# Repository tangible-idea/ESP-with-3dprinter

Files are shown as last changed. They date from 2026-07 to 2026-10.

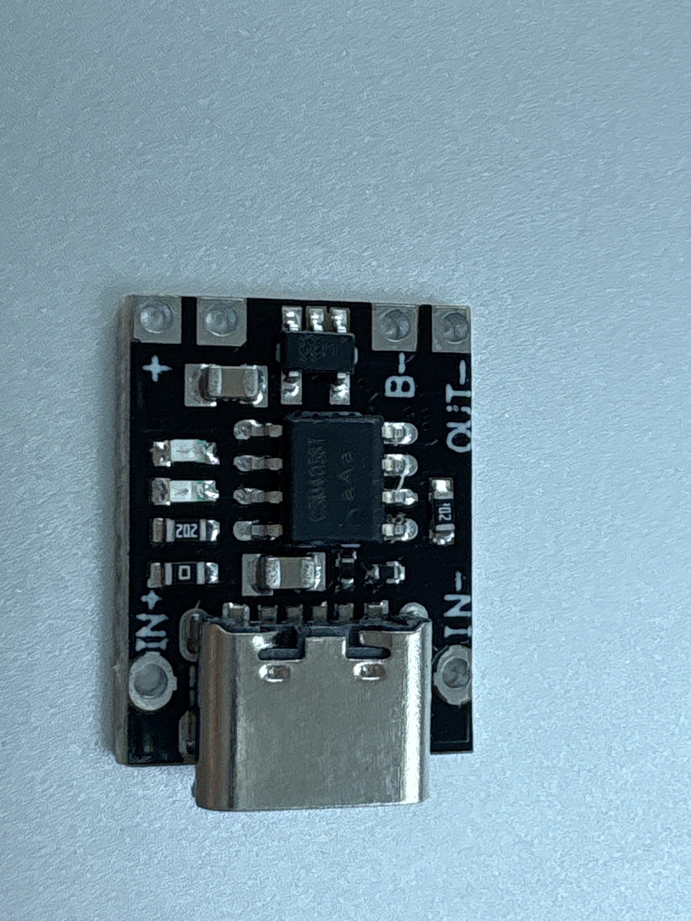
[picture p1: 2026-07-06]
hardwares/battery_charging_module.jpeg

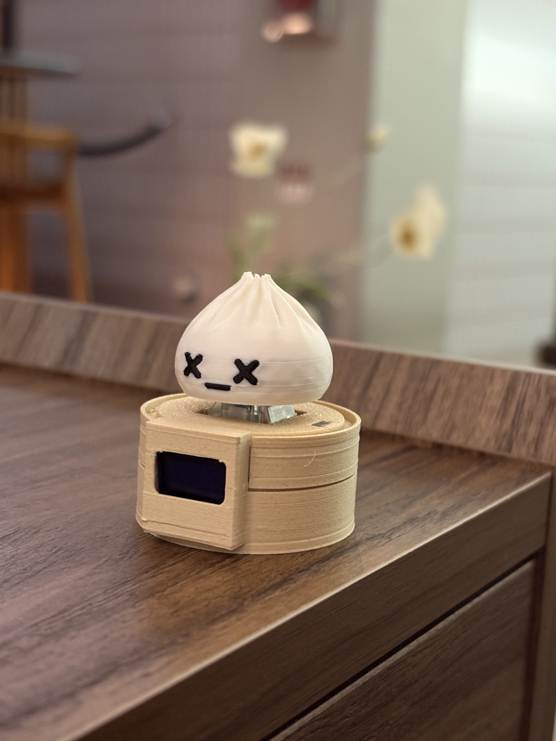
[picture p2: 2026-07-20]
hardwares/IMG_5292.jpg

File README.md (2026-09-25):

# 🥟 딤섬 클리커 (Dimsum Clicker)

딤섬 찜기 모양의 3단 적층형 하드웨어 케이스. ESP32-C3 + 520mAh 배터리 + OLED + 키보드 스위치를 담아
누르면 반응하는 미니 가젯을 만드는 프로젝트입니다.

**브라우저에서 슬라이더로 케이스를 실시간 재설계**하고 층별 STL을 바로 뽑을 수 있는 웹 컨피규레이터가 핵심입니다.

컨피규레이터의 제품 선택 메뉴에는 다음 독립 설계도 함께 들어 있습니다.

- **투두 서포터** — 아이맥 하단 모서리에 끼우는 ESP32/OLED 클립
- **운동 모션 센서** — 운동기구에 30×10×2mm 자석으로 붙이고 MPU6050으로 상하 움직임을 측정. 선택형 KY-035(15×19)는 내장 자석 옆에 세워 장착/분리를 판정합니다. 선택형 0.96" OLED는 뚜껑 위 보호 림에 끼우며 23.2×12.4mm 화면이 위로 보이고, MPU6050과 GPIO8/9 I2C 버스를 공유합니다. 기본 외형은 47×31×33.9mm입니다.

```
1층 (배터리)  ─  2층 (ESP32 · 충전모듈 · OLED · USB)  ─  3층 (뚜껑 + 스위치 스탠드 + 딤섬 캐릭터)
```

---

## 실행 방법

브라우저(three.js + WASM) 앱이라 **로컬 웹 서버만 있으면** 됩니다. 별도 설치·빌드가 없습니다.

```bash
# 1) 프로젝트 루트에서 실행 (stl_files/ 를 읽어야 하므로 반드시 루트에서)
cd ESP-with-3dprinter
python3 -m http.server 8123

# 2) 브라우저에서 접속
#    http://localhost:8123/web/
```

> Python이 없으면 아무 정적 서버나 가능합니다 — 예: `npx serve` 후 `/web/` 경로로 접속.
> 필요한 라이브러리(three.js·manifold WASM 등)는 전부 `web/vendor/`에 포함되어 있어 **인터넷 없이도** 동작합니다.

### 쓰는 순서

1. 왼쪽 패널에서 모양(둥근 네모/원형)·크기·층 높이·부품 위치를 조정 → 3D 미리보기가 실시간 갱신
2. `배선 표시`를 켜면 배터리→충전모듈→ESP32→OLED→스위치 배선이 색깔 전선으로 표시됨
   (보라 스위치 · 초록 SDA · 주황 SCL 전선을 **우클릭**하면 GPIO 핀 변경)
3. `분해 ⟷ 조립` 슬라이더로 조립 상태 확인, 하단의 `조립 간섭 없음 ✓` 확인
4. `STL 내보내기`에서 1·2·3층을 각각 다운로드 → 슬라이서로 출력
5. 마음에 드는 설정은 `프리셋 → 내보내기`로 .json 저장 (설정은 자동으로도 저장됨)

전체 기능 설명은 [`web/README.md`](web/README.md) 참고.

---

## 프로젝트 구조

| 경로 | 내용 |
|---|---|
| `web/` | **웹 컨피규레이터** (메인). `index.html` + `app.js` + `vendor/`(로컬 라이브러리) |
| `generate_dimsum_clicker.py` | 파이썬 STL 생성기 (웹과 동일한 manifold 엔진, 배치 출력용) |
| `stl_files/` | 부품 실측 STL (배터리·충전모듈·ESP32·스위치 스탠드·OLED·USB 구멍) — 케이스 절삭/배치 기준 |
| `hardwares/` | 부품 데이터시트/사진 (핀아웃, 치수) |
| `dimsum/` | 딤섬 캐릭터·클릭 캡 STL |
| `my_designs/` | 초기 손 모델링 참고본 (원형 다마고치 스타일 등) |

---

## 두 가지 생성 방식

- **웹 컨피규레이터** (`web/`) — 실시간 파라메트릭. 슬라이더로 조정하고 즉시 STL 다운로드. 평소엔 이걸 쓰세요.
- **파이썬 생성기** (`generate_dimsum_clicker.py`) — 고정 파라미터로 배치 생성.
  ```bash
  pip3 install --user trimesh manifold3d shapely
  python3 generate_dimsum_clicker.py   # output_stl/ 에 층별 STL 생성
  ```

둘 다 **manifold WASM/라이브러리**로 CSG 연산을 해서 출력 STL이 항상 watertight(출력 가능)입니다.

---

## 필요한 하드웨어 (BOM)

| 부품 | 사양 | 케이스 반영 |
|---|---|---|
| ESP32-C3 SuperMini | 24 × 18 × 4.2mm | 2층 포켓 + 핀아웃 기반 배선 |
| 리튬 배터리 | 520mAh 36.5 × 28.5 × 4.3mm / 302030 135mAh 32 × 20 × 4mm / 14280 350mAh Ø14.2 × 28.2mm / 16340 Ø16.7 × 37.4mm / 3.7V 10180 100mAh Ø10 × 18mm (원통형) / 650mAh 40 × 20 × 8mm | 선택한 규격으로 1층 테두리 또는 2층 세움 포켓 생성 |
| 충전모듈 | 기존 STL 19 × 14 × 4.5mm (칩명 미확인) / TP4056 USB-C 27 × 17.3 × 4.0mm | 2층, 선택한 모듈 치수에 맞춰 포켓과 USB 포트 생성. TP4056 실물 치수 확인 필요 |
| OLED 디스플레이 | 0.49" (15×16) 또는 0.96" (26×26) | 2층 타워에 뒤에서 삽입, 창으로 화면 노출 |
| 키보드 스위치 + 스탠드 | 17.79 × 14.3, 높이 11mm | 3층 뚜껑에 실물 형상대로 구멍 |

배선(웹의 `배선 표시` 참고). 기본 핀 배정은 **펌웨어 쪽 배선도(`wiring.html`)와 동일**합니다 — 모든 핀은 3D 뷰에서 전선/라벨 우클릭으로 변경 가능:
- 배터리 +/− → 충전모듈 **B+/B−**
- 기존 충전모듈 **OUT+/OUT−** → ESP32 **5V/GND** (기존 배선 표시). TP4056 선택 시 OUT은 배터리 전압이므로 5V 직결 안내를 표시하지 않으며, ESP32 전원 입력/필요한 승압 회로와 배터리별 충전 전류를 별도로 확인해야 함
- ESP32 **3V3·GND·GPIO8·GPIO9** → OLED **VCC·GND·SDA·SCL** (I2C)
- 스위치 2가닥 → ESP32 **GPIO3 + GND** (극성 무관 / 스위치 2개 모드는 두 번째가 **GPIO4**)
- 2×5 투톤 LED → **GPIO7 = 빨강(1번 핀, 1kΩ)**, **GPIO6 = 초록(3번 핀, 220Ω)**, 공통 캐소드(2번 핀) → GND
- 피에조 부저 + → **GPIO2** (PWM 톤), − → GND

여유 핀: **0 · 1 · 5 · 10 · 20 · 21**

```cpp
// 펌웨어 예시
Wire.begin(8, 9);          // SDA, SCL — 웹에서 바꾼 핀 그대로
pinMode(3, INPUT_PULLUP);  // 스위치: 눌리면 LOW
// GPIO2는 ESP32-C3 스트래핑 핀 — 부팅이 불안정하면 여기부터 의심
```

---

## 출력 & 조립 팁

- **1·2층은 그대로**, **3층만 뒤집어서** 출력 (상판이 베드에 닿게 — 서포트 불필요). 내보내기의 `3층 출력용 뒤집기` 체크가 처리해 줌.
- **V형 결합부**(기본 켜짐)를 쓰면 2층 밑면 결합 홈에 **서포트가 필요 없고** 층이 얹을 때 자가 정렬됩니다.
- 층이 **헐거우면** `결합 유격`을 낮추고(기본 0.08mm), **안 들어가면** 올리세요. 프린터 수축에 맞춰 조정.
- **딸각 결합**(기본 켜짐, 1↔2↔3층)은 네 코너에 **캔틸레버 스냅 후크**를 만듭니다.
  아래층 상판에서 두께 1.0mm 탄성 팔이 올라가고, 팔 끝 바깥면의 45° 비드가 위층 벽 안쪽 포켓에 물립니다.
  휘는 건 강체 턱이 아니라 팔이라서 **걸림 깊이를 0.5mm** 로 잡을 수 있습니다(강체 rabbet 에 돌기만 붙이면 0.2mm 가 한계).
  기본값에서 조립력은 층당 대략 **1~2kgf**, 팔 굽힘 변형률 0.9~1.5% (PLA 안전 범위).
  - `걸림 깊이` ↑ = 더 단단히 잡힘 / `탄성 팔 길이` ↑ = 더 부드럽게 눌림
  - 팔 길이는 위층 벽 안에 들어가도록 자동 클램프 → 낮은 층은 팔이 짧고 뻣뻣해집니다(경고로 표시)
  - 코너를 쓰는 이유: 어떤 설정에서도 USB·OLED·스위치가 닿지 않는 유일한 자리
  - 4층 뚜껑은 턱·홈만 유지합니다 — 뚜껑은 턱이 베드에 닿게 출력하므로 그 아래로 팔을 더 내릴 수 없습니다
- 각 층은 딤섬 찜기처럼 **얹으면 맞물리는** 구조라 나사·접착 없이 조립됩니다.

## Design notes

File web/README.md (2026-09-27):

# 🥟 딤섬 클리커 웹 컨피규레이터

브라우저에서 슬라이더로 케이스를 실시간 재설계하고 층별 STL을 바로 다운로드합니다.

## 실행

```bash
# 프로젝트 루트에서 (stl_files/ 를 읽어야 하므로 반드시 루트에서)
python3 -m http.server 8123
```

브라우저에서 <http://localhost:8123/web/> 접속.

## 기능

- **제품 선택**: 딤섬 클리커 / 투두 서포터 / **운동 모션 센서**. 운동 센서는 TW802040 배터리(40×20), KY-035(15×19), 선택형 0.96" OLED를 위한 3단 적층형입니다. ESP32-C3 SuperMini를 선택하면 TP4056과 MPU6050이 트레이에, SuperMini가 뚜껑에 놓입니다. Seeed XIAO ESP32C3를 선택하면 충전모듈 자리에 놓습니다. XIAO 포켓 기본값은 긴 변 X(USB 끝↔반대쪽) **22.5mm**, 짧은 변 Y(양쪽 핀 열 사이) **17.8mm**이며 두 치수를 0.1mm씩 조절할 수 있습니다. USB 개구부는 원래 나팔형 구멍보다 폭 약 0.4mm, 높이 약 0.36mm 줄였습니다. 배선 구멍은 D2/D3 근처의 보드 뒷면 B+/B− 패드 아래에 있습니다. 배터리 두 선은 D2/D3 핀이 아닌 B+/B−에 직접 연결하며 XIAO의 USB-C로 충전합니다. 이 배치에서 별도 충전모듈과 전원 스위치 자리, 뚜껑의 SuperMini 케이지는 빠집니다. **ESP 수납부 높이** 슬라이더는 선택한 보드의 수납 공간과 케이스 전체 높이를 함께 조절합니다(기본 4.6mm). OLED는 뚜껑 위에 놓이고 MPU6050과 GPIO8/9 I2C 버스를 공유합니다.

  KY-035는 3V3/GND와 아날로그 출력(GPIO0 같은 ADC 핀)으로 연결합니다. 부팅 시 내장 자석만 있는 기준값을 평균내고, 외부 자석을 붙인 상태의 값을 별도로 학습한 뒤 두 값의 중간값에 히스테리시스와 50~100ms 디바운스를 적용하면 운동 시작/끝점 오검출을 줄일 수 있습니다. 외부 자석 극성에 따라 값이 증가하거나 감소할 수 있으므로 변화 방향도 함께 저장해야 합니다.

- **모양**: 둥근 네모 / **완전 원형(딤섬 찜기)** — 원형은 W가 지름이 되고(기본 Ø54, 배터리 대각선 46.3mm 때문에 하한) D·모서리는 비활성. 원형에서는 충전모듈이 항상 중앙(Y 고정)이고 동쪽 벽에 폭 18mm 플랫 USB 패드가 생김(my_designs/rounded.png 참조). OLED 안착면은 곡률에 맞춰 자동 계산됨
- **외곽 디자인**: 가로/세로/모서리 둥글기/벽 두께/결합 유격. 결합 유격(기본 0.08mm)을 줄일수록 층이 꽉 끼움
- **V형 결합부** (기본 켜짐): 층간 홈·턱을 58° 계단 단면으로 만들어 위층 밑면에 서포트가 필요 없음 + 조립 시 자가 정렬. 끄면 기존 사각 단면
- **설정 자동 저장**: 모든 값이 localStorage에 저장되어 리로드해도 유지, '설정 초기화' 버튼으로 기본값 복원
- **미세조절**: 각 슬라이더 좌우 −/+ 버튼으로 step 단위 정밀 조정
- **프리셋 import/export**: 전체 설정을 .json 파일로 저장/불러오기 (여러 디자인 파일 관리)
- **층 높이**: 1·2·3층 + 스위치 보스 높이/스탠드 매립 깊이
- **부품 배치**: 3층 MX 스위치 X/Y(더블 모드는 두 스위치 묶음이 함께 이동), ESP32 위치·회전, 충전모듈 종류(기존 19×14×4.5 / TP4056 USB-C 27×17.3×4.0)와 Y(USB는 항상 동쪽 벽), 배터리 종류(520mAh 36.5×28.5×4.3 / 302030 135mAh 32×20×4 / 원통형 14280 350mAh Ø14.2×28.2 / 원통형 16340 Ø16.7×37.4 / 원통형 3.7V 10180 100mAh Ø10×18 / 650mAh 40×20×8) 및 1층 가로(긴 변 X)·세로(긴 변 Y)·2층 세움, OLED 종류(0.49" 15×16 / 0.96" 26×26)와 벽 선택(서쪽 기본 = USB 반대), 배선구멍 위치·방향(14×5 / 5×14 / 5×17 슬롯 — 배터리 +/− 두 가닥이 함께 통과). TP4056 옵션은 별도 실측 보드 외형이며 제품마다 크기·핀 배열이 다를 수 있어 실물 확인 필요
- **0.96" OLED**: 표시영역 22.74×11.86에 맞는 큰 창 + 모서리 4홀(22×22mm)에 맞는 Ø1.8 위치결정 핀 4개가 포켓 안에 자동 생성. 모듈이 26mm로 커서 타워가 높아지므로 2·3층 높이 경고를 확인할 것
- **OLED 타워 결합**: OLED는 타워 뒤(내부)에서 통째로 밀어 넣음 — 뒷면 완전 개방(15.5×16.3), 앞은 벽+디스플레이 창이 잡아줌. OLED 소켓은 2층 높이와 무관하게 항상 21.2mm 타워로 서고, 2층 벽보다 높으면 3층 뚜껑에 타워 모양 노치가 자동으로 커팅되어 끼워짐(조립 키 역할). 덕분에 2층을 16mm까지 낮출 수 있음
- **분해 ⟷ 조립** 슬라이더 + 애니메이션, 부품 고스트 표시, 케이스 반투명(X-ray)
- **배선 시각화** ('배선 표시' 토글): 실제 핀 배치 기반 전선 가이드 — 배터리 +/− → (2층 배선구멍 경유) → 충전모듈 B+/B−, 기존 모듈 OUT+/OUT− → ESP32 5V/GND, ESP32 3V3/GND/GPIO8/GPIO9 → OLED VCC/GND/SDA/SCL, 스위치 2가닥 → GPIO/GND (극성 무관, 3층 상판 중앙 통로 경유, 기본 G3), 2×5 투톤 LED → G7 빨강 / G6 초록 / 공통 캐소드 GND, 부저 + → G2. TP4056은 OUT이 안정화된 5V가 아니므로 ESP32 5V 직결선을 생략하고 전원 입력/승압 회로 확인 경고를 표시함. 기본 핀맵은 펌웨어 배선도(`wiring.html`)와 동일.
- **GPIO 핀 우클릭 변경**: 스위치·SDA·SCL 세 전선 모두 **우클릭하면 GPIO 선택 메뉴**가 뜨고, 고른 핀의 실제 위치로 전선이 이동. ESP32-C3는 I2C도 소프트웨어 핀이라 SDA/SCL도 자유 배정. 다른 전선이 쓰는 핀은 회색으로 비활성화되어 충돌 방지. 기본 스위치=G3(2개 모드 두 번째=G4), SDA=G8, SCL=G9, LED 빨강=G7, LED 초록=G6, 부저=G2 색상: 빨강 +, 검정 −, 초록 SDA, 주황 SCL, 보라 GPIO. 핀 라벨 스프라이트 포함, 분해 뷰를 따라감
- **부저 핀 구멍**: 2층 바닥 세움은 받침 바닥을 관통하는 구멍 2개, 2층 눕힘은 핀이 나오는 +X 끝면의 축방향 구멍 2개. 기본 핀 간격 6.5mm·구멍 Ø1.5mm이며 설정에서 실물 치수에 맞출 수 있음. 3층 천장 매달림은 핀이 빈 공간을 향해 상판을 뚫지 않음. NFC 포켓과 겹치면 경고 표시
- **측면 텍스처 (Weave 1·2·3 · Wood 1)**: 버튼 하나로 케이스 **바깥 옆면에만** 무늬를 새김. **케이스 외곽선(원통/둥근 네모) 위에 있는 면에만** 들어감 — OLED 타워·커버, 플랫 USB 패드, 결합 턱/홈처럼 외곽선에서 벗어난 면과 위·아래 면, 포켓 안쪽 벽은 매끈하게 남아서 층 결합·부품 끼움이 그대로 유지되고, 무늬는 **안쪽으로만** 파내므로 바깥 치수도 커지지 않음. 깊이·무늬 크기·디테일(mm/삼각형) 조절 가능. 무늬를 고르면 그 이미지에 맞는 무늬 크기·디테일이 자동으로 들어감 — 이미지 한 장 안의 반복 횟수가 달라서(Weave1 8회 / Weave2 6회 / Weave3 12회 / Wood1 29회) 같은 값을 쓰면 Weave3·Wood1 은 무늬 한 칸이 1mm 아래로 잘아져 뭉개짐. Wood 1 은 흑백 2치 나뭇결이라 결이 가로로 케이스를 감아 돎(tile 36 / 디테일 0.4) 무늬가 켜져 있으면 슬라이더를 드래그하는 동안에는 형상만 빠르게 갱신하고, 손을 떼면 CSG를 다시 돌리지 않고 무늬만 다시 입힘
- **조립 간섭 자동 검사**: 리빌드마다 층간 교집합 부피를 계산해 하단에 "조립 간섭 없음 ✓" 표시
- **STL 내보내기**: 층별 다운로드, 3층은 출력용 뒤집기 옵션 (크롬이 연속 다운로드를 차단하면 주소창의 다운로드 아이콘에서 허용)
- 배터리/부품이 안 들어가는 조합이면 하단에 경고 표시

## 구현

- CSG 엔진: **manifold WASM** (`vendor/manifold.wasm`) — 파이썬 생성기(`generate_dimsum_clicker.py`)와 동일 엔진이라 출력 STL이 항상 watertight
- 3층 스위치 자리는 `stl_files/keyboard_switch_stand.stl` 실물 메시를 3.5% 팽창시켜 그대로 boolean 절삭 → 스탠드가 보스에 자연스럽게 매립
- USB 구멍도 `stl_files/usb_c_hole.stl` 실물 형상 사용 (얇은 벽에 맞게 나팔부 60% 압축)
- 모든 라이브러리는 `vendor/`에 로컬 포함 — 오프라인 동작
- 측면 텍스처는 `texture.js` — 꼭짓점 용접 → 옆면 마스크(법선이 거의 수평 + XY 반직선으로 바깥 실루엣만 선별 + 호출부가 준 `opt.skip`: app.js 는 둥근 사각형 부호거리로 "외곽선에서 0.35mm 이내"인 면만 통과시킨다) → red-green 적응 세분화 → 트라이플래너 UV 로 높이맵 샘플 → 수평 법선 방향 변위. 높이맵은 최소/최대가 아니라 2%/98% 지점으로 오토레벨해서 JPEG 잡티가 대비를 잡아먹지 않게 함. 마스크 경계 꼭짓점은 고정이라 watertight 이 유지됨. [CNCKitchen/stlTexturizer](https://github.com/CNCKitchen/stlTexturizer) 의 파이프라인을 참고했고, `textures/` 의 weave 3장 + wood 1장은 해당 저장소(AGPL-3.0)에서 가져온 displacement map

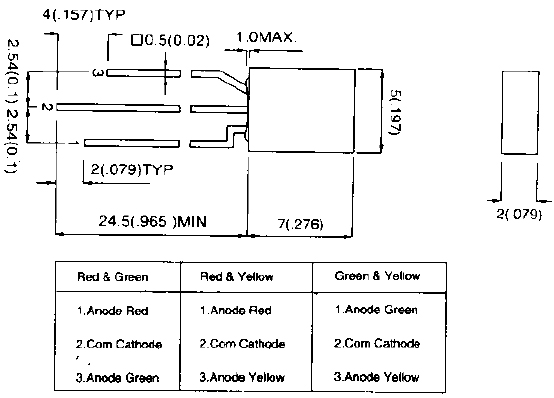
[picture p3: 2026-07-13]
hardwares/led_2x5.png

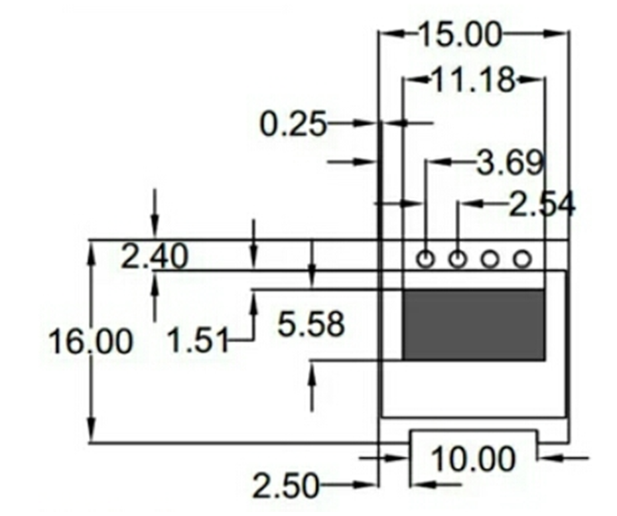
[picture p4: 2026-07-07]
hardwares/oled-0.49.png

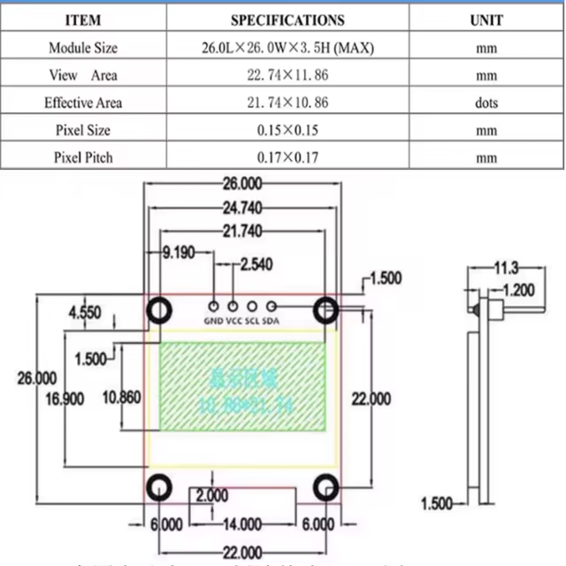
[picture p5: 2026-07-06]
hardwares/oled-0.96.png

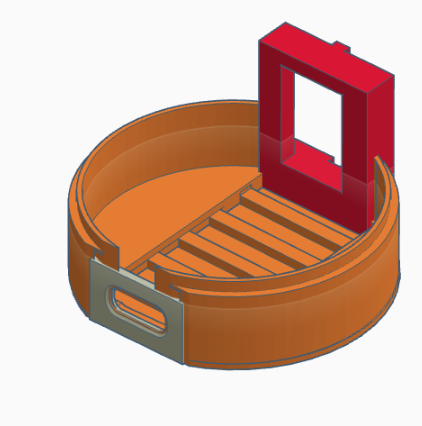
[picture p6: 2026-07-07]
my_designs/rounded.png

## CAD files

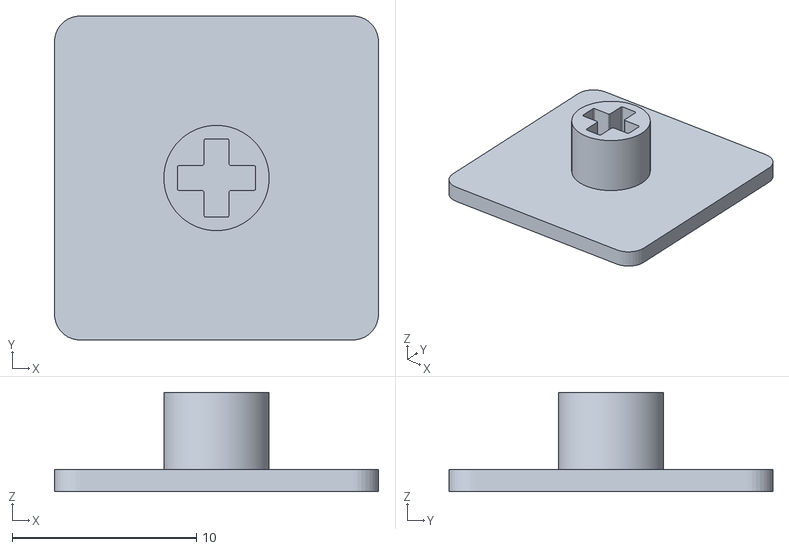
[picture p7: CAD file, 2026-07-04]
dimsum/obj_3_click.stl
17.6 x 17.6 x 5.38

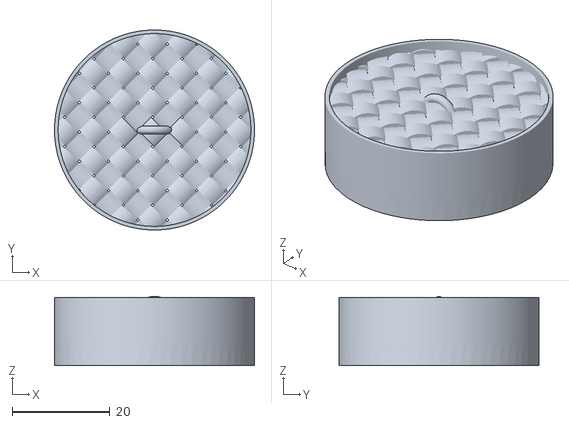
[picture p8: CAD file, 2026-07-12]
my_designs/bun_lid.stl
41.0 x 41.0 x 14.2

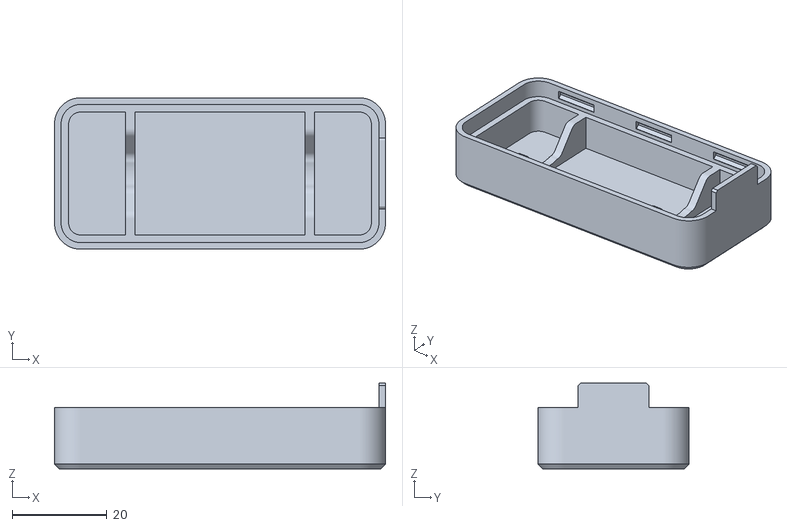
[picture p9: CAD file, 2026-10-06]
my_designs/moisture/xiao-soil-sensor-buttom-3d-printed.stl
70.0 x 32.0 x 18.1

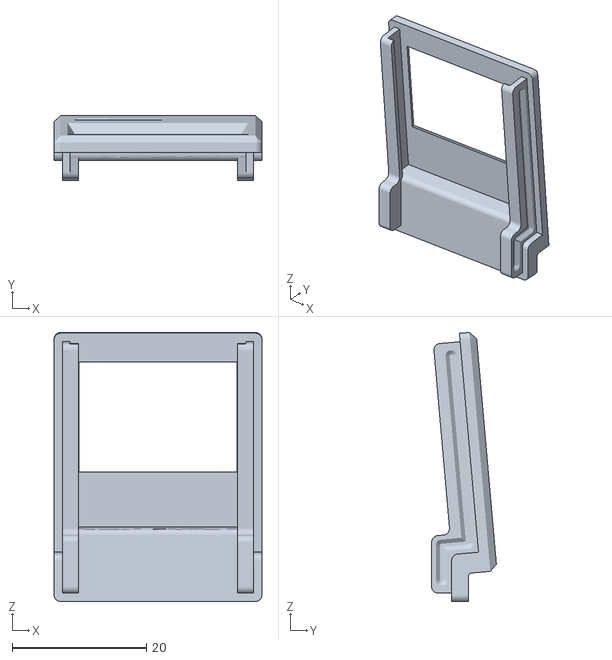
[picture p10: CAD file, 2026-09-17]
stl_files/Tinytosh+-+Cover.stl
31.0 x 9.66 x 40.1

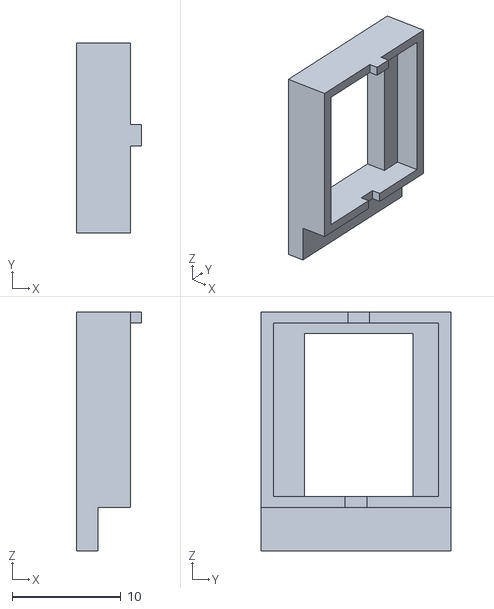
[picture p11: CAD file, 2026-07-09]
web/Project Gasi (97).stl
6.00 x 17.5 x 22.0

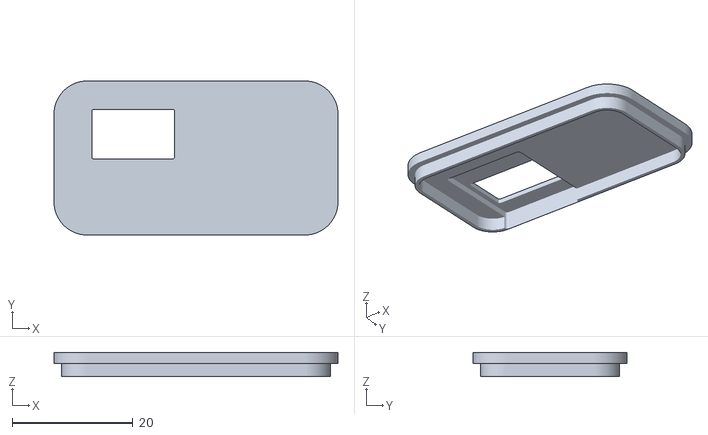
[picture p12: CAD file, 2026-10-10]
workout_sensor_xiao_oled049_lid.stl
47.0 x 25.5 x 4.00

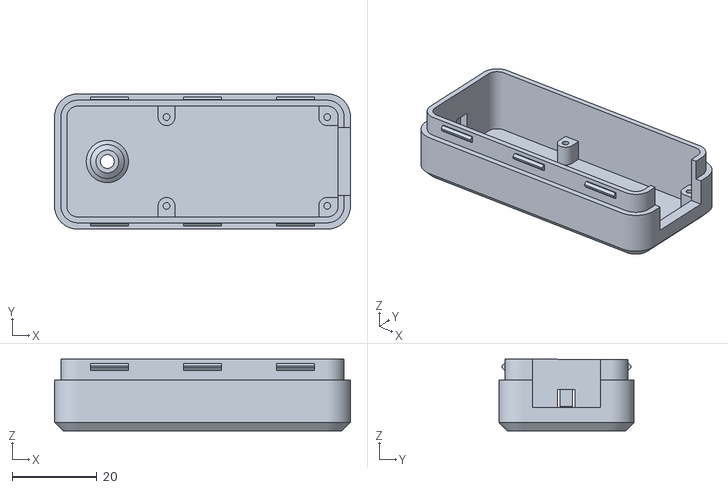
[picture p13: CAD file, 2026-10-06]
my_designs/moisture/xiao-soil-sensor-top-3d-printed.stl
70.0 x 32.0 x 17.0

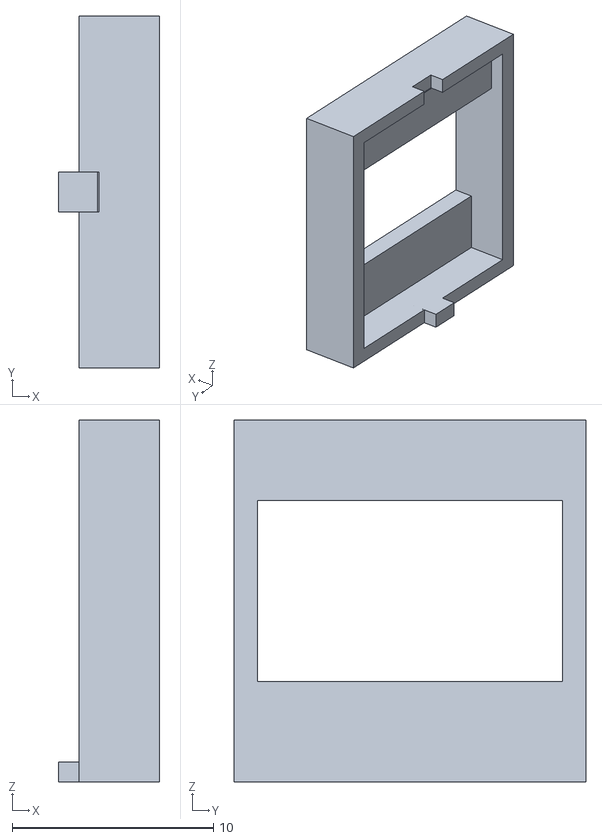
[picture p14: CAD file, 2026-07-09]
my_designs/window_cover_for_oled0.49.stl
5.00 x 17.5 x 18.0

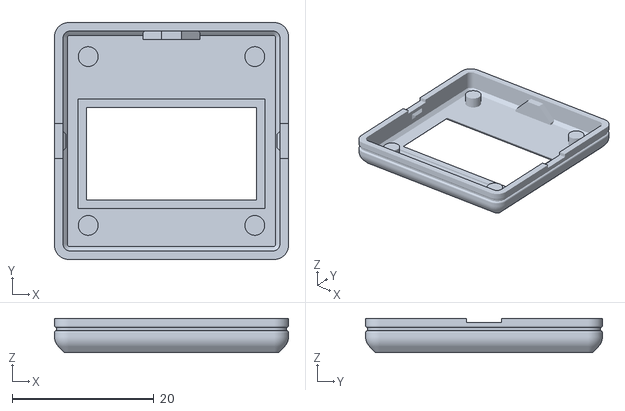
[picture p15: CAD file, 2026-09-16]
stl_files/obj_2_Oled-Lid.stl
33.0 x 33.4 x 4.80

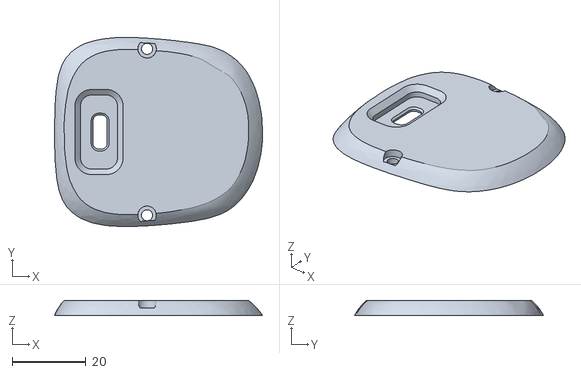
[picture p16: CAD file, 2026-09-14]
stl_files/yeti_cover.stl
56.2 x 51.1 x 4.00

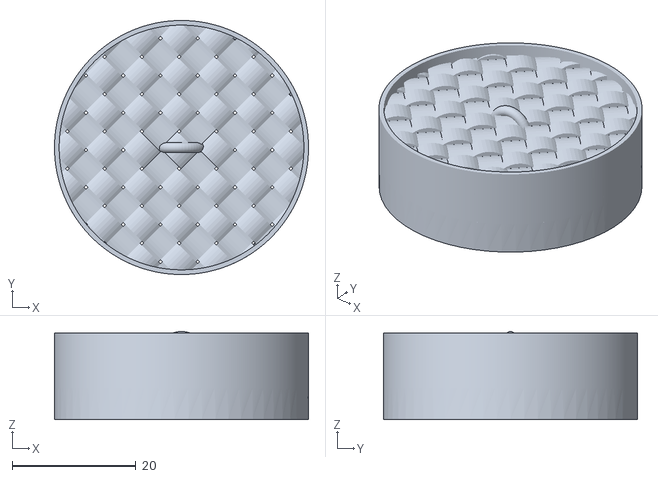
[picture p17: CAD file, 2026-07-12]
web/dist/assets/bun_lid_clean-BYsGTvJL.stl
41.0 x 41.0 x 14.2

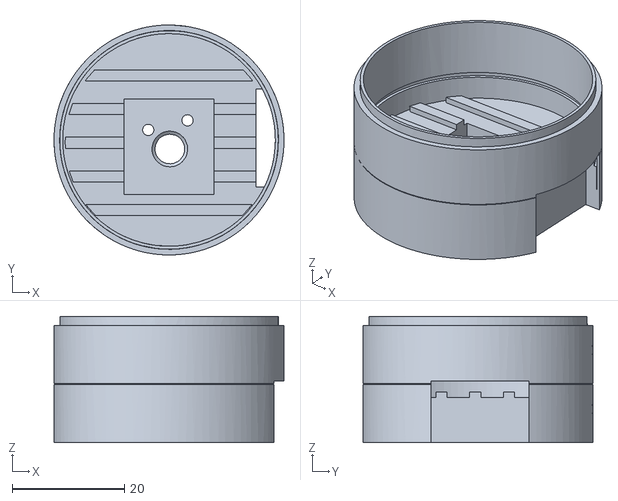
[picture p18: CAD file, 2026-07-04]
my_designs/3rd_floor_keyboard_switch_base.stl
41.0 x 41.0 x 22.5

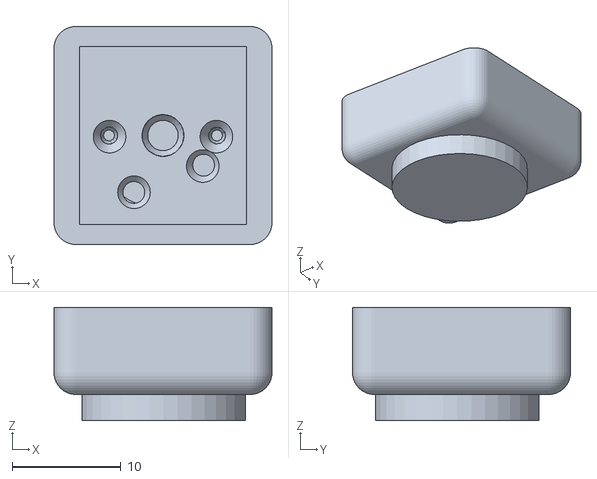
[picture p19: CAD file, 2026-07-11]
stl_files/Mechanical Key Holder V3.stl
20.0 x 20.0 x 10.4

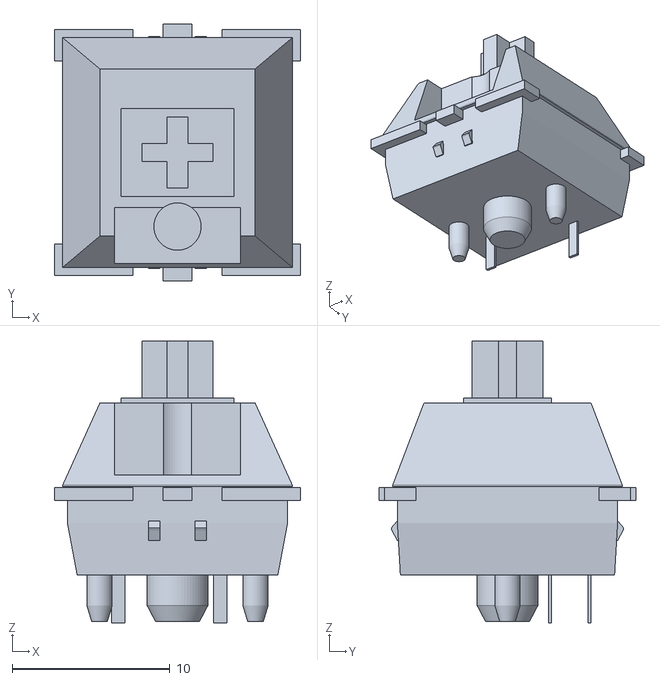
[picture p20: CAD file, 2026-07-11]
web/dist/assets/switch_mx-DlXkNR-Z.stl
15.6 x 16.3 x 17.9

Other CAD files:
my_designs/2nd_floor_esp32_base.stl
stl_files/520Mah_battery.stl
stl_files/keyboard_switch_stand.stl
stl_files/oled_0.49inch.stl
web/dist/assets/battery_charging_module-BhVwN-nm.stl
web/dist/assets/esp32_c3_supermini-DsPQz_9p.stl
web/dist/assets/obj_2_sup 2.0 face-BjSeTE-s.stl
web/dist/assets/usb_c_hole-Bh-LhuL4.stl

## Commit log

2026-07-04 first commit.
    [2nd_floor_esp32_base.stl, 3rd_floor_keyboard_switch_base.stl, 520Mah_battery.stl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]
2026-07-04 사각 모양으로 디자인 변경
    [assembly_preview.stl, floor1_battery.stl, floor2_esp32.stl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]
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2026-07-07 평면 벽 세그먼트를 바닥(z=0)까지 내렸습니다 — 결합 V홈이 이 평면 벽을 자연스럽게 관통하면서 아래층 턱과의 결합도 그대로 유지됩니다
2026-07-07 esp32 와 oled 하단부분이 겹칠떄는 esp32부분 홈을 더 우선적으로 판다.
    [assembly_preview.stl, floor1_battery.stl, floor2_esp32.stl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]
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2026-07-07 수치 조절 pane 쪽 width를 더 넓혀주고, 각 슬라이더에 +, - 를 두어서 미세조절할 수 있게 해줘. 전체 preset을 import export할 수 있게도 해줘
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2026-07-11 oled 벽 두께 수정.
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2026-07-11 2.5층
    [Mechanical Key Holder V3.stl, switch_mx.stl]
2026-07-11 받침선 + USB 앵커 블록 + 셸 실루엣 홈 + 양옆 스냅 립
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2026-07-12 뚜껑 추가
    [bun_lid.stl, bun_lid_clean.stl]
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2026-07-12 추가했습니다. '부품 배치 (2층)'에 ESP32 Z 미세조정 슬라이더(−1 ~ +2, 0.1 단위)가 생겼습니다.
    동작 방식: 슬라이더를 올리면 ESP32가 앉는 포켓 바닥이 그만큼 올라가서(포켓을 얕게 파서) 보드 전체가 위로 올라갑니다. 고스트와 배선 핀 위치도 함께 따라갑니다. 모든 배치 모드에 적용됩니다 — 지금 쓰시는 도킹(USB 직결) 모드는 물론, 눕힘/세움/띄움(2.5층)에서도 동일하게 동작합니다.
    중요한 점 하나: USB 구멍의 z는 일부러 고정했습니다. 실물에서 보드가 낮게 앉아 USB가 구멍 아래쪽에 치우치는 걸 보정하는 게 목적이라, 보드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
2026-07-13 배선 표 안된건가?
    [battery_charging_module-BhVwN-nm.stl, bun_lid_clean-BYsGTvJL.stl, esp32_c3_supermini-DsPQz_9p.stl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]
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2026-07-18 Add a rim ring to steamer floor slats for a level printing surface
    - Adds a border ring at slat height around the steamer floor ribs so the outer edge sits flush with rib tops when printed upside down
    - Grooves are now trimmed to stay inside the ring boundary instead of the old wall/lid offsets
    - Rebuilds web/dist bundle to match
2026-07-19 OLED 분리 포드(소켓형) 추가 + 소켓 슬림화
    - oledPodOn: OLED 타워(창·포켓·핀 포함)를 별도 출력 파트로 분리
    - 텅(전면부)이 벽 관통 개구를 지나 외곽면과 플러시, 어깨가 벽 안쪽에 걸림
    - 안쪽 U자 소켓 레일(1.2t, 높이 최대 8)에 위에서 슬라이드, 3층 노치가 잠금
    - oledCavityCut(b, withPegs) 공용화, checkFit에 포드 간섭 검사, ex5 내보내기
    - LED 구멍 여유 +0.2→+0.3
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2026-07-24 추가한 내용
    제품 선택 → 세부 설정의 깊은 메뉴 구조
    - 패널 최상단에 Product(제품) 선택기 추가: Dim Sum Clicker / Todo Supporter (iMac).
    - 선택에 따라 data-product 섹션이 전환됩니다 (딤섬 4개 섹션 ↔ 투두 4개 섹션). View·Presets·Settings는 공용.
    - 기본값을 새 제품(투두)으로 설정해 바로 보이게 했습니다. 딤섬으로 전환하면 기존 메뉴·배선표·모델이 그대로 복귀합니다.
    모니터 투두 서포터 — 아이맥 우측하단 코너 ㄷ자 클립
    - 코너 클립 & 물림: 기기 폭 / 아이맥 모서리 두께(기본 11.5) / 슬롯 유격 / 벽 두께 / 바닥 브릿지 / 모서리 둥글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
2026-07-24 todo supporter: usb 부분 수정.
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2026-07-28 투두 서포터: OLED 정면 복원 + 통일 폭 31 + 상단 챔퍼 + 숨은 배선 통로
    - ㄷ 클립을 부품 폭 기준 통일 폭으로: OLED 켜면 31mm, 끄면 24mm 슬림
    - 앞벽=OLED 하우징(창이 +Y 사용자 정면), 뒤벽=ESP32 포켓 통합, 단차 제거
    - 앞·뒤 벽 상단 45° 챔퍼(chamferBox) — union 전 홀로 깎아 무한평면 침범 방지
    - USB-C: 나팔형 툴 길이축 축소로 바닥면에 입구 정렬(투박한 슬롯 제거)
    - OLED↔ESP32 숨은 배선 통로: 슬롯 아래 브릿지 관통, 밖으로 노출 없음
    - dist 재빌드, 한/영 힌트 갱신, 프리뷰 이미지 2장 추가
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2026-08-20 USB 패드 전진배치·깔때기 목 전진, NFC 중앙 버튼
    - USB 패드 바깥으로 밀기(usbPadOut) 추가: 안쪽면(ESP32 도킹 기준면)은 고정하고
    바깥면만 내보내 패드가 그만큼 두꺼워짐. 기본 1.0 → 패드 2.5→3.5
    - 깔때기 목 위치를 슬라이더로(usbThroat): 하드코딩 -1.5를 빼내 기본 0(최대 전진).
    목이 바깥면에서 5.0→3.5mm 로 나와 플러그 오버몰드 자리가 생김
    - 포트 둘레 남길 벽 기본 1.2→1.5 (범위 ~3.0)
    - USB 패널을 결합부 한계까지 위아래로 확장 — 중간에 끊긴 단(경계선) 제거
    - NFC X/Y 아래 "중앙으로" 버튼 추가
    - 벽 두께 경고 수정: 패널 깊이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
2026-08-27 - OLED 기판: 25 × 27.05 × 3.5mm - 화면 노출부: 23.2 × 12.4mm - 뚜껑 위 보호 림에 OLED를 위에서 삽입 - 화면은 위쪽으로 완전히 보이도록 배치 - OLED 배선 4가닥은 뚜껑 슬롯을 통해 ESP32로 연결 - MPU6050과 GPIO8 SDA / GPIO9 SCL I2C 버스 공유 - OLED를 끄면 받침·화면·배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
    기본 크기는 OLED 사용 시 47 × 31 × 33.9mm, 미사용 시 47 × 31 × 29.7mm입니다.
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2026-09-14 ESP32를 뒤집어 2.5층 받침에 끼울 때, USB 셸 아래 홈을 최대 0.8mm 더 깊게 파도록 모델 코드
2026-09-14 yetti_cover 참조 추가.(맘에안든다)
    [yeti_cover.stl]
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2026-09-15 이 요청은 코드 계획 작업이 아니라 커밋 메시지 생성 요청이네요. Plan mode 지시와 무관하게 바로 답변만 드리면 됩니다
    Thin down floor-2 base plate, refine USB-C shell cutout, rebuild bundle
    - Drop the general F2 floor thickness to 0.8mm while keeping part
    seating, OLED tower, NFC pocket, and buzzer sockets on raised pads
    at the original 2.0mm reference height, so existing pocket depths
    and Z offsets stay unchanged.
    - Replace the lifted ESP32's boxy USB-C cutout with a rounded
    extruded-profile cut that matches the real connector shell shape.
    - Rename hardwares/yeti_cover.stl to stl_files/yeti_cover.stl and
    rebuild the web/dist bundle.
    [yeti_cover.stl]
2026-09-15 Add cable channel for buzzer wire and raise ESP32 lift-slot rear stopper
    - Replace hidden buzzer wire notch with an open T-shaped cable channel
    cut through to the socket ring top, matching intended visuals, and
    extend NFC-pocket collision checks to cover the new channel shape
    - Raise only the far-side (non-USB) shoulder of the ESP32 lift slot by
    3mm so the flipped board seats more securely, and tighten the
    length-wise fit clearance from 0.4mm to 0.2mm
    - Route the buzzer cable groove up to the flipped ESP32's USB pocket
    when the board is lifted, so the wire has a path instead of being
    trapped under the board
    - Add dimsum preset (16).json snapshot and rebuild web/dist bundle
2026-09-16 ESP32 insertion bar clearance (mm)
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2026-09-16 0.96″ OLED 고정 기둥 4개의 지름을 참조 STL 실측값에 맞춰 Ø1.8mm → Ø2.8mm로 굵게 변경
    [obj_2_Oled-Lid.stl]
2026-09-16 OLED 테스트 STL 내보내기를 수정 (결합)
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2026-09-17 Replace 0.96" OLED peg mount with a slide-in channel
    - 4-hole positioning pins were finicky to align; switched to a
    bottom-slide channel guided by two rear ribs instead
    - update UI copy (EN/KR) and rebuild web/dist bundle
    - adds dimsum_character.glb and Tinytosh cover STL as reference assets
    [Tinytosh+-+Cover.stl]
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2026-09-19 Increase TP4056 pocket rear clearance to fit real board length
    - MOD_POCKET_BACK_CLEAR raised from 1.5mm to 2.0mm to match the measured 28.2mm total pocket length for the TP4056 module
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2026-09-25 Add battery types and 3rd-layer switch X/Y placement to configurator
    - Add 302030, 14280, 16340 and 10180 battery options, including cylindrical pockets, ghosts and wiring.
    - Add Switch X/Y sliders that move the holder, boss, steamer slats and wires together.
    - Add warnings for the switch–OLED tower overlap and the switch character touching the outer wall.
    - Raise the Layer 1 height slider max to 20 to fit the taller cells.
    - Update the READMEs and rebuild web/dist.
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2026-09-25 Add XIAO onboard-charging dock mode to configurator
    - XIAO charges the battery through its back-side BAT+/BAT− pads, so no
    charge module is needed even with a battery. Introduce noMod() so the
    ESP32 docks to the wall USB hole in that case, like the no-battery mode.
    - Replace noBat() with noMod() in the docking, pocket, USB hole, ghost
    and warning code; battery pose stays gated on noBat().
    - Wire table and 3D wires now show battery → XIAO BAT+/BAT− pads.
    - Clamp the dock Y when the ESP type changes, sharing clampDockY() with
    the battery type handler.
    - Rename the "USB push-out" label from "no battery" to "docked" (EN/KO).
    - Rebuild web/dist bundle.
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2026-09-27 Add adjustable XIAO pocket dimensions and refine wire-hole/USB cutout ge
    - Expose XIAO pocket X/Y as sliders (defaults 22.5×17.8mm) instead of hardcoding board size, replacing the previous fixed 22.7×18mm footprint
    - Correct battery pad wire-hole placement to sit near D2/D3 pads instead of guessing a symmetric offset, and shrink the USB cutout slightly for XIAO
    - Update Korean/English UI hints to describe the new pocket controls and correct wiring guidance (connect to B+/B-, not D2/D3 pins)
    - Rebuild web/dist bundle to match app.js changes
2026-09-28 Add adjustable XIAO clip hook to workout case dividers
    - Extend the divider bars' upper ends with a small hook that projects
    toward the XIAO pocket and presses on the board's rear edge, holding
    it in place without a separate retainer.
    - The hook has a flat underside just above the PCB and a 45° top face,
    so the board is inserted USB-end first and snaps in when the rear
    end is pressed down. The 1mm overhang prints without supports.
    - Add a "wkClipLip" slider (0–1.2mm, default 0.6) with EN/KO labels;
    it is enabled only in XIAO mode, and 0 removes the hook.
    - Raise the divider bar height as needed to fit the hook, capped by
    the existing lid-cage limit.
    - Rebuild web/dist bundle.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
2026-10-05 Add XIAO through-hole, tray floor, and MPU/charger pocket options
    - XIAO pocket floor is now open to layer 1 so the board can pass
    through tilted; laid flat it rests on adjustable X-end ledges
    (wkXiaoLedge). This replaces the small fixed battery wire slot.
    - Add wkTrayFloor to set the layer 2 floor thickness; the floor is
    split between pocket depth, layer 1↔2 joint depth and cover. The
    joint is dropped below ~0.8 mm and deepens up to 2.2 mm when thicker.
    - Add wkMpuPocket for independent MPU6050 pocket depth, shifting the
    MPU inward when it would overlap the joint groove.
    - Add a charge module selector (TP4056 27×17.3 or generic 19×14×4.5)
    and a wkChgLedge seat ledge limitin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
2026-10-05 Add charger size and MPU peg sliders; make tray floor joint deeper
    - Add charger long/short side sliders (wkChgW/wkChgD) that resize the
    pocket, wire hole and seat ledge. Switching module resets them to that
    module's default size.
    - Add MPU6050 peg diameter and inset sliders for the two locating pegs
    on the +X corners of the MPU pocket.
    - Raise the tray floor default to 3.4 mm so the layer 1↔2 joint stays
    2.2 mm deep. Thinner floors now remove the board pockets first and
    the joint last. A new wkRev 9 migration resets saved floors to 3.4.
    - Shorten the base tongue by 0.2 mm so it still seats if the groove
    ceiling bridge sags.
    - Clamp the switch window height so wall remains abov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
2026-10-05 Raise ESP USB slot fit and ESP section depth defaults so printed cases f
    - Printed USB-C slot came out 0.1-0.2 mm narrower than modeled, so the
    ESP32 would not fit. wkUsbFit now defaults to +0.3 (was -0.2), the
    slider range extends to 1.0, and the label reads "USB slot fit
    (+ = looser)".
    - ESP section height defaults to 5.2 (was 4.6). A 4.2 mm board had only
    0.2 mm of clearance, too tight for a real part.
    - The ESP board seat height now follows the cage depth (espZ0), so a
    deeper cage keeps the board against the lid top and puts the spare
    clearance on the open underside.
    - Add saved-settings migrations (wkRev 10 and 11) that update only
    values still at the old defaults, leaving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
2026-10-05 Add SuperMini pin-through-lid mode with OLED lift option
    - Solder the SuperMini header on the component side so the 16 pins pass through holes in the lid plate. New options: pin-through toggle, pin hole size (default Ø1.2) and OLED lift height.
    - Raise the OLED on corner posts above the pin tips, so the protruding pins don't touch the board. The ghost preview, wiring anchors and total height all account for the lift.
    - Add warnings for a header body that hits the lid plate, and for pins that need trimming to clear the OLED.
    - Add a settings migration (rev 13) that moves the old 1.5 and 1.0 pin hole defaults to 1.2. Printed 1.0 holes shrank too much for the 0.64 square pins.
    - Rebuild the di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
2026-10-06 xaio 식물센서 디자인
    [xiao-soil-sensor-buttom-3d-printed-DWCdrrpG.stl, xiao-soil-sensor-buttom-3d-printed.stl, xiao-soil-sensor-top-3d-printed-Kl38Ld8K.stl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]
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2026-10-10 Add ESP32-S3 1.14" TFT board option to workout sensor
    - New "tft" ESP type (50.8×22.9) lies screen-up in the tray with USB-C
    toward the -X wall. Its onboard IMU and charger replace the MPU6050
    and charge module, so those pockets, the power switch and the OLED
    options are disabled for this board.
    - Tray gets an open-floor pocket between X-end ledges for back-side
    parts and battery wires, plus PH2.0 plug room and a wire slot.
    - Lid gets an LCD-pressing boss and a 45° chamfered display window;
    connector height, LCD offset and window size/position are sliders.
    - Add TFT pin map, wiring table, ghost parts, fit warnings and
    EN/KO strings; widen the case automatically when the board i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
    [workout_sensor_xiao_oled049_lid.stl]
2026-10-10 Add TFT corner rounding option and fix USB-C fit
    - Add a "Corner rounding" slider (wkRound, default 5.5) for the workout
    case, shared by base, tray and lid via a single caseR helper.
    - Set the TFT USB end gap to 0 so the USB-C plug seats fully in the
    wall hole, and center the USB-C jack on the short side (usbY = 0).
    - Migrate saved settings: reset the old 3mm gap and revert the
    mis-measured LCD center X (5.2 back to 6.4).
    - Drop the lid boss that pressed on the LCD glass; the display window
    now cuts through the lid plate only, with the 45° chamfer kept.
    - Rebuild dist bundle.
2026-10-10 Add USB wall tab to TFT workout case and rebuild web dist
    - Raise the wall around the TFT USB hole to lid-top height; the wall there was only ~1mm thick after the lid joint groove was cut.
    - Cut a matching pocket in the lid so it seats over the tab with fit clearance.
    - Add the tab after the joint groove is cut and before the USB hole, so the groove doesn't shave it.
    - Rebuild web/dist; the bundle hash changes and index.html is updated to match.
2026-10-10 Shorten USB tab so lid top skin stays closed
    - Limit the TFT USB wall extension to rise into the lid plate rather than reaching its top surface, leaving a 1.0mm skin (new USB_TAB_SKIN).
    - Cut the lid's matching pocket from below only up to rise + 0.2, so it no longer punches through the top surface.
    - Rebuild web/dist with the updated bundle.
2026-10-11 Add Google Drive sync and per-design saved versions to the web UI
    - Add web/cloud.js: Google Identity Services sign-in (drive.appdata
    scope only) and save/load of one designs.json in the user's hidden
    Drive app folder. No server needed; the client ID comes from
    VITE_GOOGLE_CLIENT_ID.
    - Keep a saved version per design (dimsum/todo/workout/plant). Controls
    that differ from it are highlighted, each with a ↺ revert button, plus
    "Set as saved version" and "Revert all" actions.
    - When signed in, working values and saved versions auto-upload (debounced).
    On sign-in the newer side wins per design.
    - Split preset import into applyPreset() so it can be reused.
    - Add the sync bar UI, EN/K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
2026-10-11 Add XIAO 1.14" button cap catch slider and ring
    - Add a "button cap catch" slider (wkX114BtnCatch, 0–0.4mm, default 0.15) to the XIAO 1.14" options, with EN/KO labels, and disable it with the other XIAO 1.14" controls when that board isn't selected.
    - Give each button cap stem a small retaining ring above the lid plate so caps no longer fall inward when the lid is lifted or flipped. The ring is slightly larger than the hole, so it snaps in when pushed through from inside. The 45° underside and gentle top slope print without supports.
    - Make the preview ghost use the same cap geometry as the printed part, so the ring shows in the viewer.
    - Rebuild web/dist with the new bundle.
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2026-10-25 XIAO 1.14" 옆 버튼 C 손톱 홈
    - 옆 버튼 C 창을 둥근 경기장 모양으로 바꾸고, 벽 바깥으로 갈수록 1/4 타원 필렛 단면으로 부드럽게 넓혀 손톱이 미끄러져 들어가게 함
    - 벌어짐 크기 슬라이더 wkX114BtnScoop (0–2.5, 기본 1.8, 0이면 기존 직사각 창). 결합 홈·바닥·둥근 모서리에 닿지 않게 자동 제한
    - 프리셋 JSON과 web/dist 갱신
2026-10-25 XIAO 1.14" 옆 전원 스위치 슬라이더 제거, 스위치 자리 벽으로 덮음
    - +Y 벽에는 옆 버튼 C 손톱 홈 창만 남기고 스위치 창·삽입 가이드를 없앰
    - 뚜껑의 이탈 방지 막대, 별도 출력 슬라이더 캡과 STL 내보내기 버튼, 관련 슬라이더·경고·문구 제거
    - xiao-switch-slider.js 삭제, 프리셋에서 wkX114Sw* 키 제거, web/dist 갱신
2026-10-25 키링 고리: 튀어나온 탭 대신 1층 +X 끝면 안 반원 링 터널
    - +X 끝면에 Y로 나란한 구멍 두 개가 안에서 U자로 이어져 키링을 가로로 꿰어 건다. 외형 밖으로 튀어나오는 부분 없음
    - 단면은 위가 45° 물방울이라 서포트 없이 출력. 배터리 포켓까지 0.8 남기도록 자동으로 덜 묻음
    - 슬라이더: 터널 지름(wkLoopD), 링 반지름(wkLoopR), 높이(wkLoopZ), Y 위치. wkLoopRim/wkLoopT 제거
2026-10-25 UDO 로고 윤곽 데이터(udo-logo.js)와 README 설명 추가
    workout.js가 불러오는 udo-logo.js가 저장소에 빠져 있어 빌드가 깨지던 문제 수정.
2026-10-25 뚜껑 조임 돌기(wkLidGrip) 추가, XIAO 1.14 핀 소켓 유격 기본 0.15로 마이그레이션
2026-10-25 UDO 로고: 베이스 + 로고 인레이를 파트 2개짜리 3MF 한 파일로 내보내기
    별도 로고 STL 버튼을 없애고, 로고가 켜져 있으면 베이스 내보내기가
    components 오브젝트로 묶인 .3mf(베이스 검정 / 인레이 #CAFA68)를 만든다.
    fflate(three 동봉)로 zip, 꼭짓점 중복 제거.
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2026-10-26 UDO 로고: 앱 헤더와 같은 소문자 "udo" (Roboto w800, 자간 -1.5/27)로 교체
    ../udo 앱 sensor_dashboard.dart _header 기준. 글자를 em 단위·줄 상자 중앙 기준으로
    다시 뽑고, 배치도 대문자 높이 대신 폰트 크기 27/38 비율로 바꿨다.
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
